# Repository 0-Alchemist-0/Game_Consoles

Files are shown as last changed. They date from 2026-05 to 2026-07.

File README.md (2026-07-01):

# Game Consoles

Custom WiFi handheld game consoles built with an Arduino Nano ESP32, a
Waveshare 3.5 inch ILI9488 SPI display, FT6336 capacitive touch, microSD RAW
assets, and a buzzer.

Current sketch: `Game_Consoles.ino`

Current firmware metadata:

- Version: `Version 9.3`
- Build ID: `GC-V93-2026070120`
- Build ID format: `GC-V<major><minor>-<YYYYMMDDHH>`

## Overview

The project boots into an arcade-style home screen, plays an optional RAW565
intro from the SD card, and provides a multi-page games menu. Games can be
played locally on one console or, where supported, over WiFi using Host/Join.

The UI is designed for portrait mode:

- Screen width: `320`
- Screen height: `480`
- Rotation: `0`
- Display colors are inverted in firmware with `INVERT_DISPLAY_COLORS = true`

The sketch draws directly to the display using targeted redraws and game-level
dirty rectangles. It does not use the old full-screen canvas framebuffer
approach described by earlier README versions.

## Hardware

Main board:

- Arduino Nano ESP32

Display:

- Waveshare 3.5 inch SPI TFT
- Controller: ILI9488
- Library class: `Arduino_ILI9488_18bit`

Touch:

- FT6336 capacitive touch controller
- I2C address: `0x38`

Storage:

- microSD card on the same SPI bus as the display
- SD assets are RAW565 files, usually `320x480`

Audio:

- Buzzer on GPIO4
- Used for menu clicks, SFX, and the background menu melody

## Pin Configuration

The sketch uses ESP32 GPIO numbering.

| Function | GPIO | Arduino Nano ESP32 label | Header note |
| --- | ---: | --- | --- |
| LCD CS | 21 | D10 | JP2-3 |
| LCD DC | 18 | D9 | JP2-4 |
| LCD RST | 17 | D8 | JP2-5 |
| LCD MOSI | 38 | D11 / MOSI | JP2-2 |
| LCD MISO | 47 | D12 / MISO | JP2-1 |
| LCD SCLK | 48 | D13 / SCK | JP1-1 |
| SD CS | 8 | D5 | JP2-8 |
| Touch INT | 6 | D3 | JP2-10 |
| Touch RST | 7 | D4 | JP2-9 |
| I2C SDA | 11 | A4 / SDA | JP1-8 |
| I2C SCL | 12 | A5 / SCL | JP1-9 |
| Buzzer | 4 | A3 | JP1-7 |

SD SPI frequency:

```cpp
static const int SD_SPI_FREQ = 49000000;
```

If the SD card is unstable with your wiring, lower this value in the sketch.

## Required Libraries

Install these in Arduino IDE / Arduino CLI:

- `Arduino_GFX_Library`
- ESP32 board package for Arduino Nano ESP32

The sketch also uses standard ESP32/Arduino libraries:

- `Wire`
- `WiFi`
- `Preferences`
- `SPI`
- `SD`
- `FS`
- `esp_now`
- `esp_wifi`
- `esp_system`

## Main Screens

Home screen:

- `GAMES`
- `SETTINGS`
- `EXIT`
- Version and Build ID are displayed in small text at the bottom

Games menu pages:

- Page 1: Tic Tac Toe, Rock-Paper-Scissors, Tanks Wars
- Page 2: Snake, Breakout, Pong, Ranch Rush
- Page 3: Hex Pipes, Frogger

Most game menus use:

- `LOCAL`
- `HOST`
- `JOIN`
- `RESET SCORE`
- `BACK`

## Settings

The Home screen `SETTINGS` button opens two settings categories.

### Music

- `MUSIC ON/OFF`
- `SFX ON/OFF`

Music controls the background arcade melody while not in a game.
SFX controls button and game sound effects.

Settings are saved persistently in ESP32 flash using `Preferences`.

### WiFi

WiFi settings allow:

- Default Host SSID selection from the built-in epic SSID list
- Host IP editing through four numeric fields
- Numeric keypad input
- Save button

Default Host IP:

```text
192.168.10.1
```

Network password for Host and Join:

```text
Alchemist2026
```

Network TCP port:

```text
3333
```

## Network Flow

Host:

1. Select `HOST` from a game menu.
2. Select an SSID from the built-in list.
3. Confirm or edit the Host IP.
4. The console starts a WiFi access point.
5. The host waits for the opponent.

Join:

1. Select `JOIN` from a game menu.
2. Scan/select an available WiFi network.
3. Confirm or edit the Host IP.
4. Join connects using the fixed password `Alchemist2026`.
5. The game starts when the socket connects.

The shared WiFi game protocol uses line-based TCP messages over port `3333`.

## Games

| Game | Local | Network Host/Join | Notes |
| --- | --- | --- | --- |
| Tic Tac Toe | Yes | Yes | Local X/O play, WiFi X/O play, persistent score |
| Rock-Paper-Scissors-Lizard-Spock | Yes | Yes | Uses SD RAW result images when available |
| Tanks Wars | Yes | Yes | Artillery-style tanks, destructible terrain, synced terrain seed |
| Breakout | Yes | Yes | First network player to lose all lives loses |
| Pong | Yes | Yes | Host-authoritative ball physics and synced paddles |
| Snake | Yes | Yes | Two-player network snakes with different colors |
| Ranch Rush | Yes | Yes | Lane-based lasso game with two visible network players |
| Frogger | Yes | Yes | Two visible network frogs, shared lanes/logs |
| Hex Pipes | Yes | Yes | Shared puzzle seed, P1/P2 move counters, solve race |

Each game has a score reset option in its game menu. High score or score data is
stored in ESP32 flash with separate `Preferences` namespaces per game.

<p align="center">
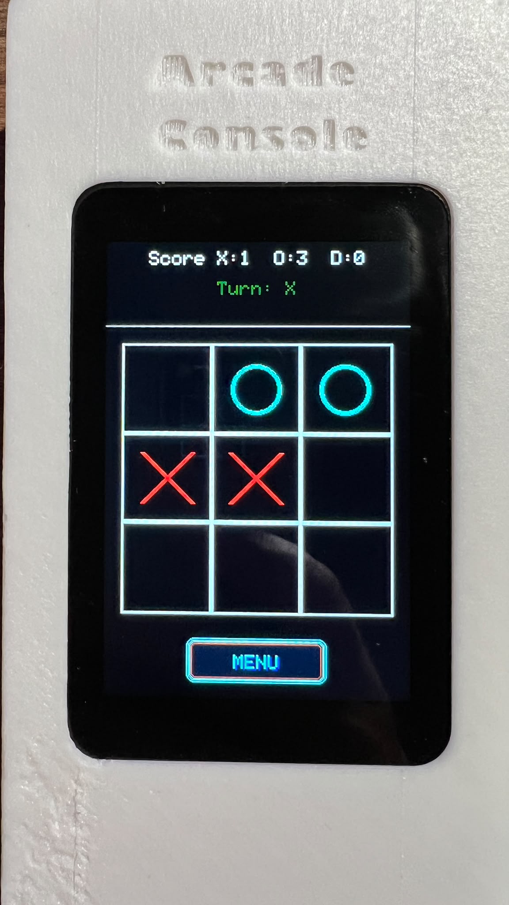
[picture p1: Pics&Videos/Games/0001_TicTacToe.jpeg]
  
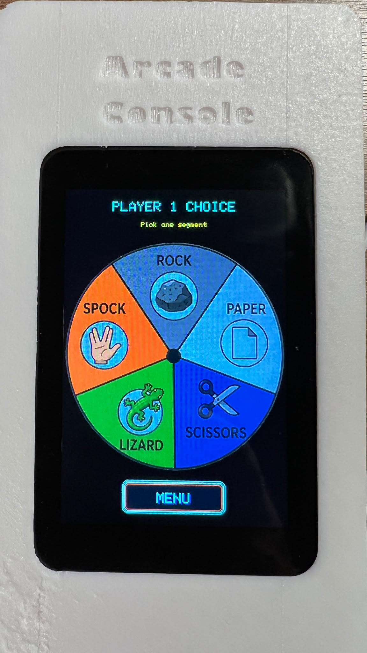
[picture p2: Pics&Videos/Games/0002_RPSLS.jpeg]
  
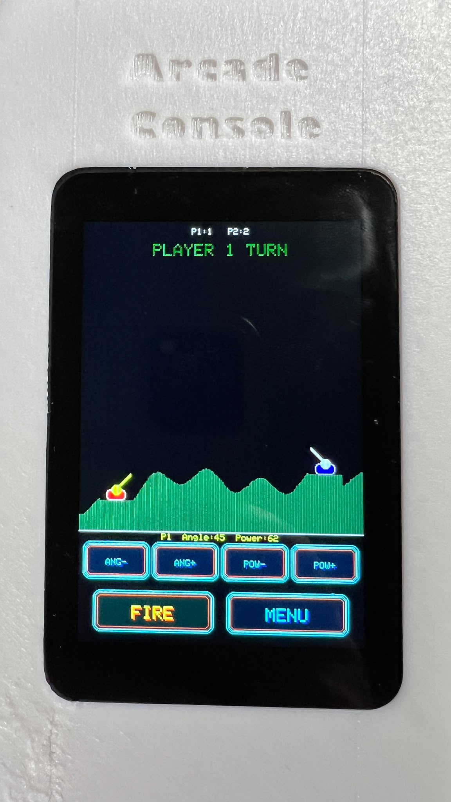
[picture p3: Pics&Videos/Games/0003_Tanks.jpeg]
  
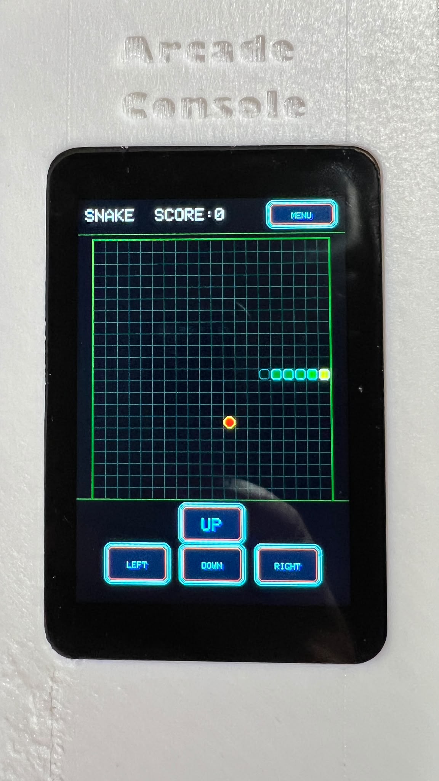
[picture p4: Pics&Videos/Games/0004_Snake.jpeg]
  
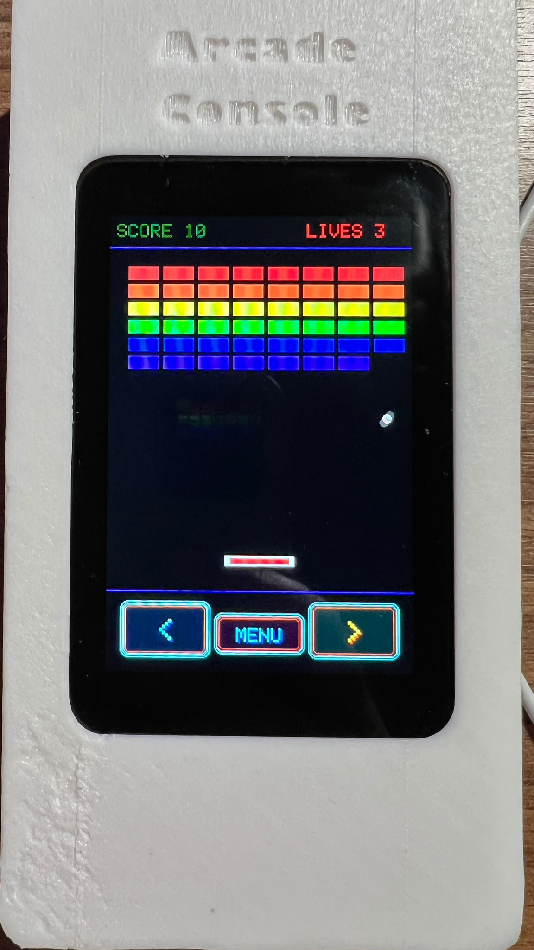
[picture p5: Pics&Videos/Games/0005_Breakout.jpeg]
  
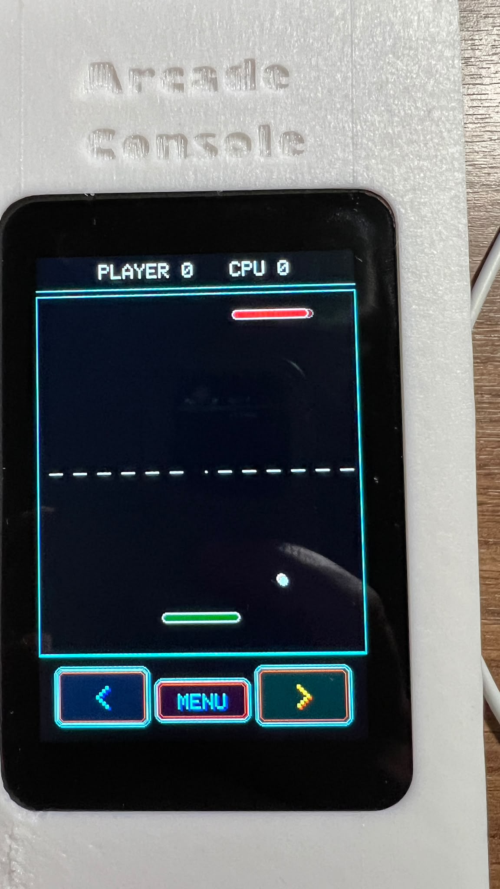
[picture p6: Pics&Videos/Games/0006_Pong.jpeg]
  
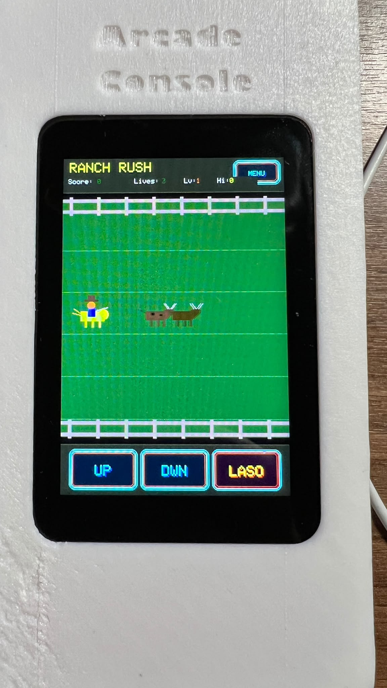
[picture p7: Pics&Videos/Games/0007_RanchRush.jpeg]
  
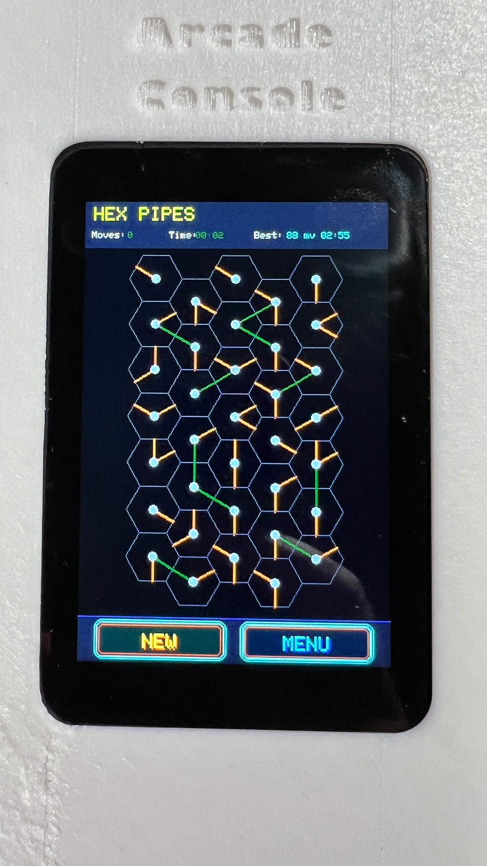
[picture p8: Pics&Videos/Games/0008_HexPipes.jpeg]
  
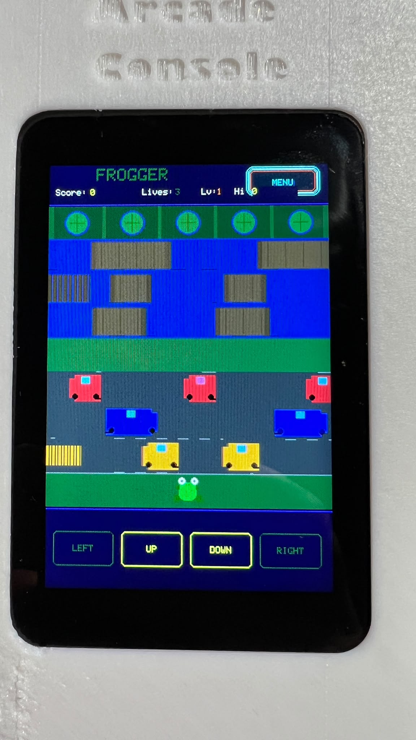
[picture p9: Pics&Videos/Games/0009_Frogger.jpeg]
  
</p>

## SD Card Assets

The console can run with generated fallback screens when assets are missing, but
the intended UI uses RAW565 files from the microSD card.

Important SD paths:

```text
/intro/frame_000.raw ... /intro/frame_074.raw
/home_screen/background.raw
/home_screen/button_games.raw
/home_screen/button_settings.raw
/home_screen/button_exit.raw
/games_screen/games_background.raw
/tictactoe_game/tictactoe_background.raw
/RPSLS_game/main_screen/rock_paper_scissors_background.raw
/RPSLS_game/general/rpsls_wheel.raw
/RPSLS_game/local/player1_wins/*.raw
/RPSLS_game/local/player2_wins/*.raw
/RPSLS_game/local/draw/*.raw
/RPSLS_game/win/*.raw
/RPSLS_game/lose/*.raw
```

RAW image format:

- RGB565
- No header
- Full-screen assets are `320x480`
- Intro frames are also portrait `320x480`

The repository `SD_card` folder contains SD card content and preview PNGs.

## Persistent Data

Stored with `Preferences`:

- Tic Tac Toe score
- RPSLS score
- Tanks Wars score
- Breakout high score
- Pong score
- Snake high score
- Ranch Rush high score
- Frogger high score
- Hex Pipes best moves and best time
- Default WiFi/Host IP settings
- Music and SFX settings

## Notes

- Keep only one active Arduino sketch file in the project folder to avoid
  duplicate symbol errors.
- The active sketch should be `Game_Consoles.ino`.
- If you copy the project into Arduino IDE, the folder name should match the
  active `.ino` file or you should open the correct sketch directly.
- If SD assets do not load, the firmware falls back to generated screens for
  the main UI and several game menus.
- For network play, use the same firmware version on both consoles.

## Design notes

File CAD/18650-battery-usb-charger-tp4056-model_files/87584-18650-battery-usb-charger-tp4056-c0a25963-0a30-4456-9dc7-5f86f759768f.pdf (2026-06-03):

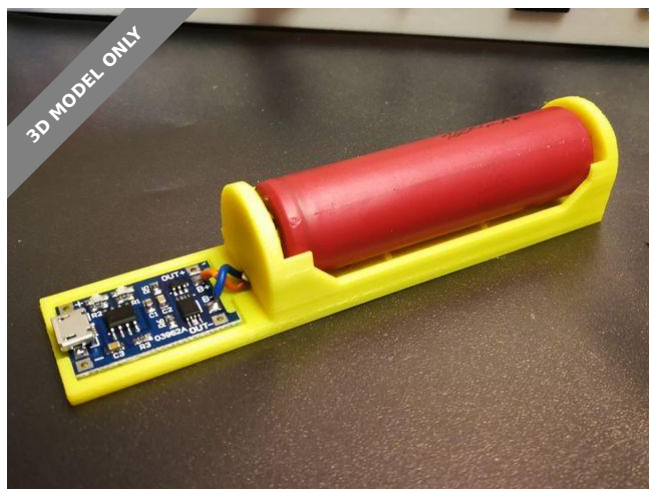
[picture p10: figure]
3D MODEL ONLY

### Summary

This is a charging holder for a single 18650 lithium ion battery. It uses the TP4056 charging board, that you can get...

Hobby & Makers (https://printables.com/model?categoryId=48) > Electronics (https://printables.com/model?categoryId=52)

Tags: 18650 | 18650battery | charger | contact | lithium
lithiumion | lithiumbattery | usb | thingiverse

This is a charging holder for a single 18650 lithium ion battery. It uses the TP4056 charging board, that you can get easy on eBay.
(Search for "lithium usb charger" or "TP4056")

The battery contacts used are 10x10mm but you can use whichever one you want.

The standard version fits unprotected cells of 65mm length, the "_protected" version fits protected cells of 68mm length

If you need one of my things printed or you want to suggest a modification on a part please drop me a message!

If you print one of my things i would be happy about some feedback and a make!

Chrismettal - Binary-6 (https://printables.com/@ChrismettalBinary6)

## 18650 Battery USB

### Charger TP4056

VIEW IN BROWSER (https://printables.com/model/87584-18650-battery-usb-charger-tp4056)

updated 6. 5. 2023 | published 6. 5. 2023

## Model files

If you like my things please consider supporting my caffeine addiction! (https://github.com/Chrismettal#donations)

### This remix is based on

18650 Battery USB Charger TP4056 by Chrismettal

Find source .stl files on Thingiverse.com (https://www.thingiverse.com/thing:2248981)

### License

This work is licensed under a
Creative Commons (4.0 International License)

Attribution-ShareAlike (http://creativecommons.org/licenses/by-sa/4.0/)

✖ | Sharing without ATTRIBUTION
✔ | Remix Culture allowed
✔ | Commercial Use
✔ | Free Cultural Works
✔ | Meets Open Definition

single_18650_v3.stl

single-18650_protected-v3.stl

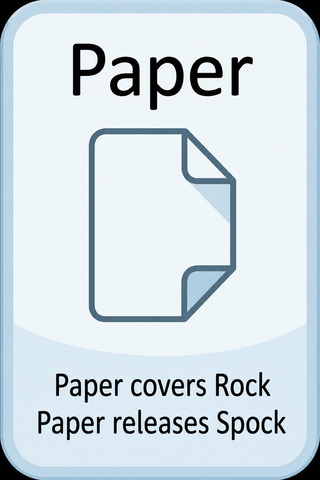
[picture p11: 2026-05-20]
SD_card/RPSLS_game/general/paper_preview.png

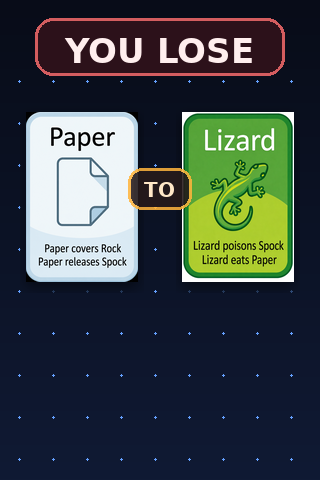
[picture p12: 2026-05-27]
SD_card/RPSLS_game/lose/lose_paper_to_lizard_preview.png

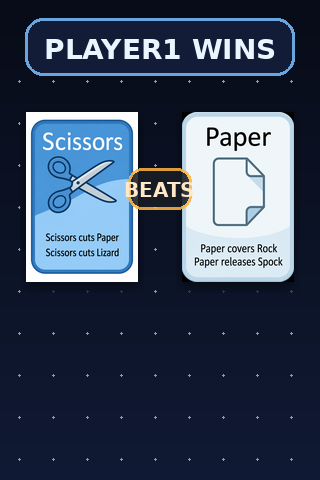
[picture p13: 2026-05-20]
SD_card/RPSLS_game/local/player1_wins/win_scissors_cuts_paper_preview.png

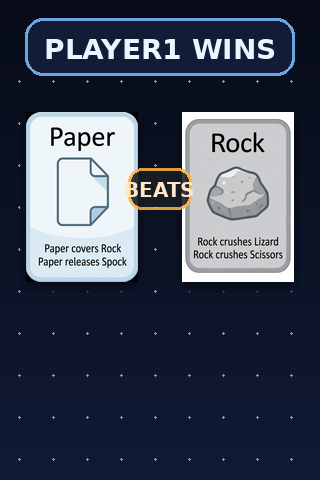
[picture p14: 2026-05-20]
SD_card/RPSLS_game/local/player1_wins/win_paper_covers_rock_preview.png

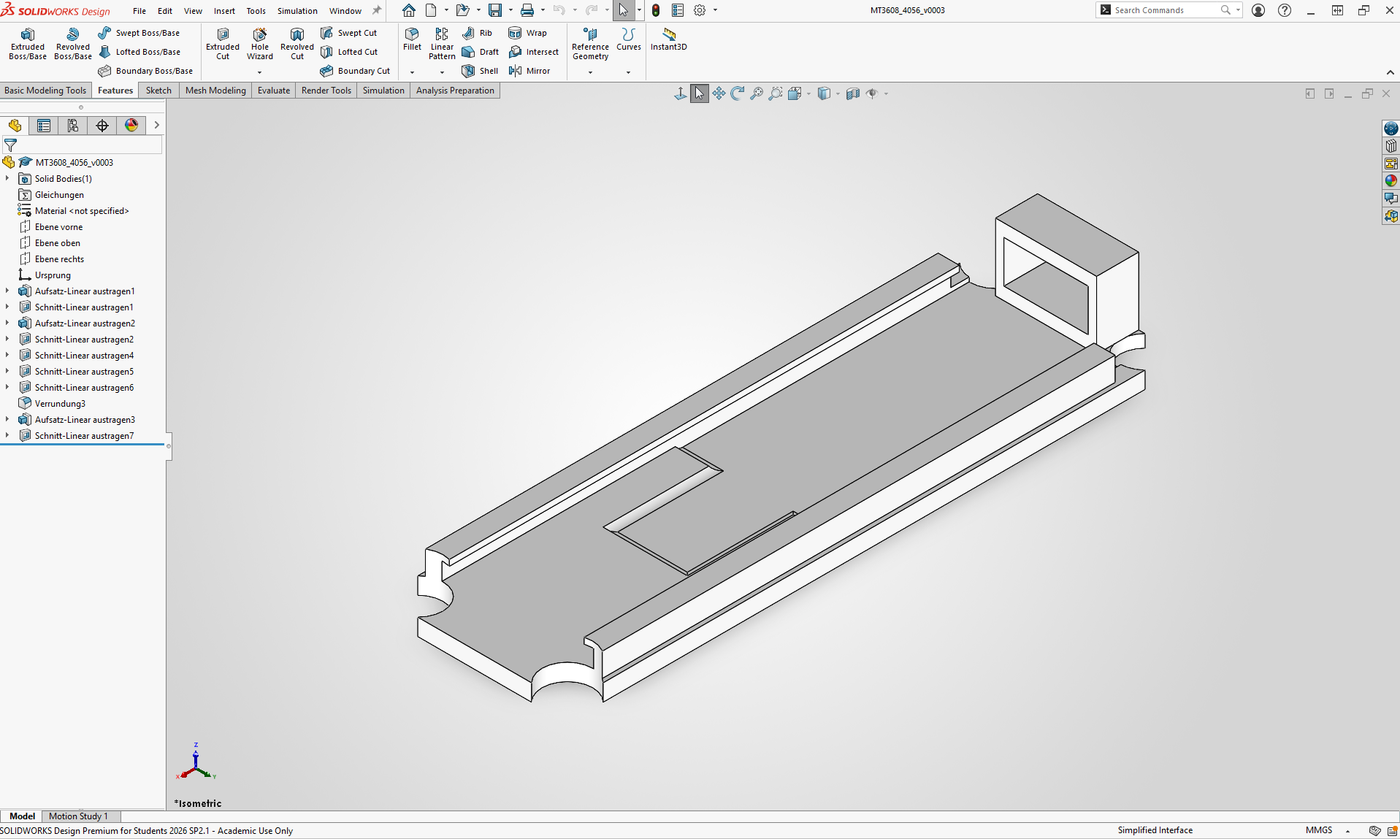
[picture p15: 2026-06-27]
Pics&Videos/00007_Support rail for the power module, designed for internal placement of the MT3608TP4056-related electronics..png

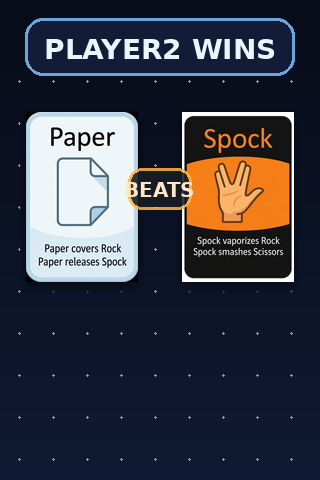
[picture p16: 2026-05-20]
SD_card/RPSLS_game/local/player2_wins/win_paper_releases_spock_preview.png

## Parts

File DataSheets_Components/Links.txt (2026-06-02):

https://docs.arduino.cc/hardware/nano/

https://www.waveshare.com/3.5inch-capacitive-touch-lcd.htm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

https://lvgl.io/tools/imageconverter
https://sourceforge.net/projects/lcd-image-converter/

https://www.printables.com/model/553096-tp4056-usb-c-model-li-ion-charge-circuit-3d-model/files
https://www.thingiverse.com/thing:1029881
https://www.printables.com/model/87584-18650-battery-usb-charger-tp4056
https://www.printables.com/model/1004227-lithium-battery-charger-li-ion-module-tp4056-usb-c/files
https://www.printables.com/model/131214-18650-minimal-holder

https://www.printables.com/model/59190-1s2p-18650-vase-mode-holder-with-tp4056-mt3608-boa
https://www.printables.com/model/1009486-enclosure-for-arduino-nano-esp32

Informatii USB-C https://electronics.stackexchange.com/questions/534304/finding-the-exterior-dimensions-of-a-usb-type-c-receptacle

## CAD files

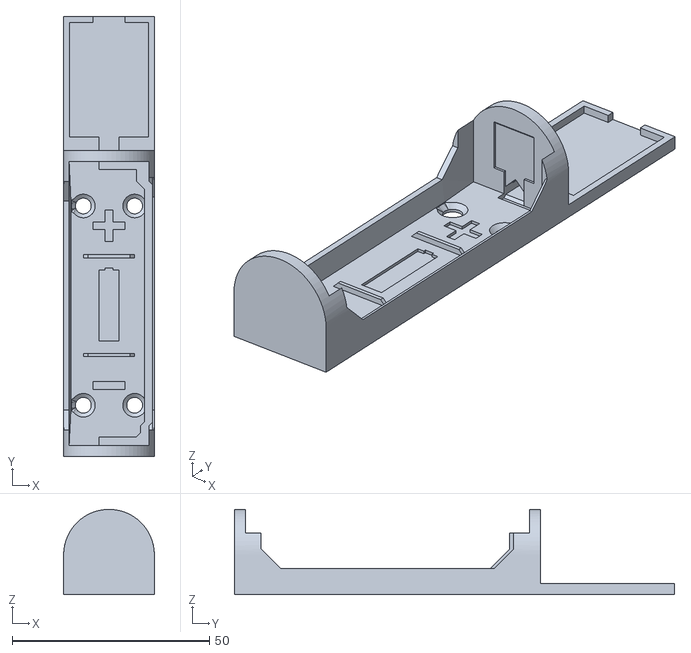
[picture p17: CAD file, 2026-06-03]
CAD/18650-battery-usb-charger-tp4056-model_files/Single 18650_Protected v3.stl
23.0 x 111.5 x 21.6

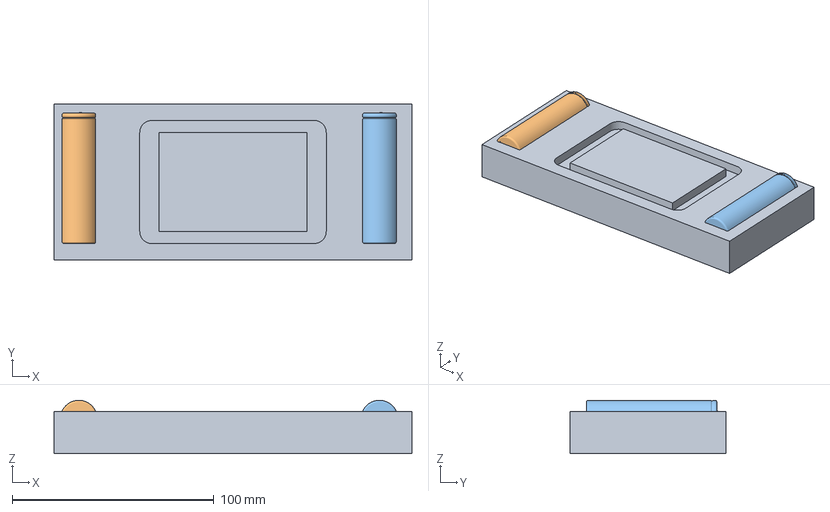
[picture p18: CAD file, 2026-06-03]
CAD/Carcasa_v0002.FCStd
177.4 x 77.5 x 26.4 mm
18650_Refrence_Cell
18650_Refrence_Cell001

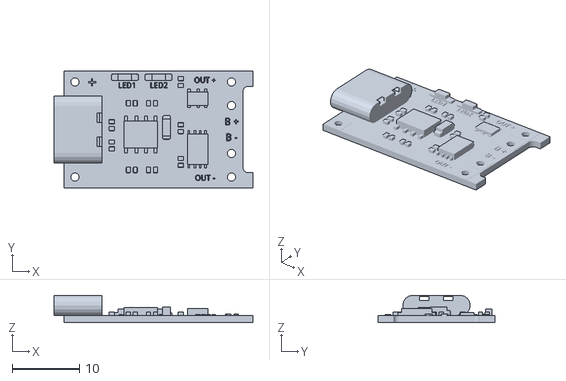
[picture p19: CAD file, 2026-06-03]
CAD/lithium-battery-charger-li-ion-module-tp4056-usb-c-mock-up-model_files/liion-charge-module-hw-373-usb-c.stl
29.5 x 17.3 x 4.07

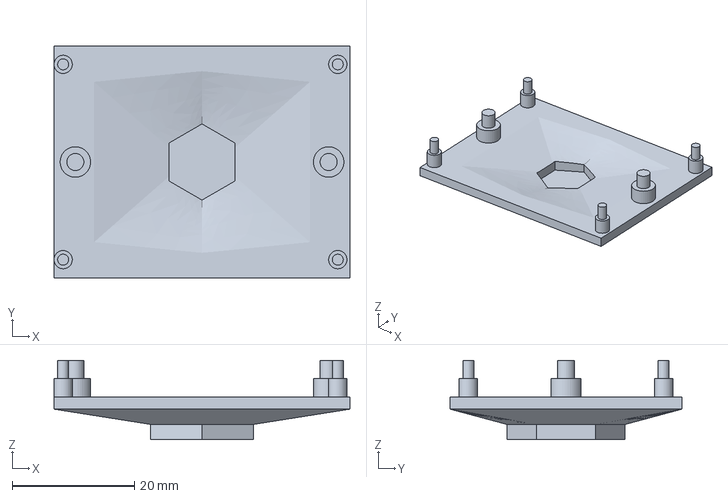
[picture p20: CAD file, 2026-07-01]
SolidWorks/Creality/Arhiva/Support_PCB_v0004.3mf
48.5 x 38.0 x 13.0 mm

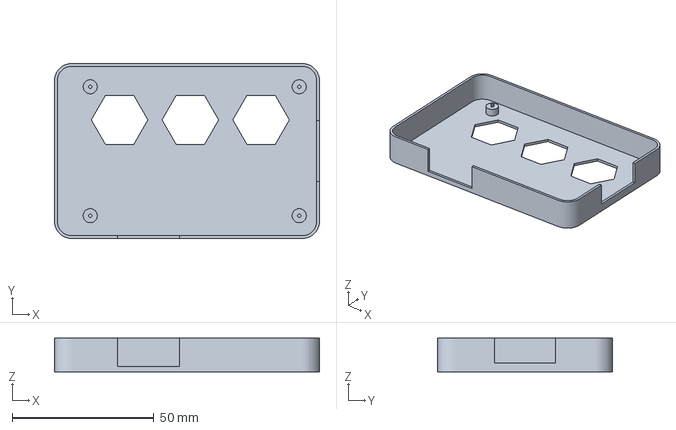
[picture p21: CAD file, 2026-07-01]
SolidWorks/Creality/Inside_Nano_Support_v1000.3mf
93.6 x 61.8 x 12.0 mm

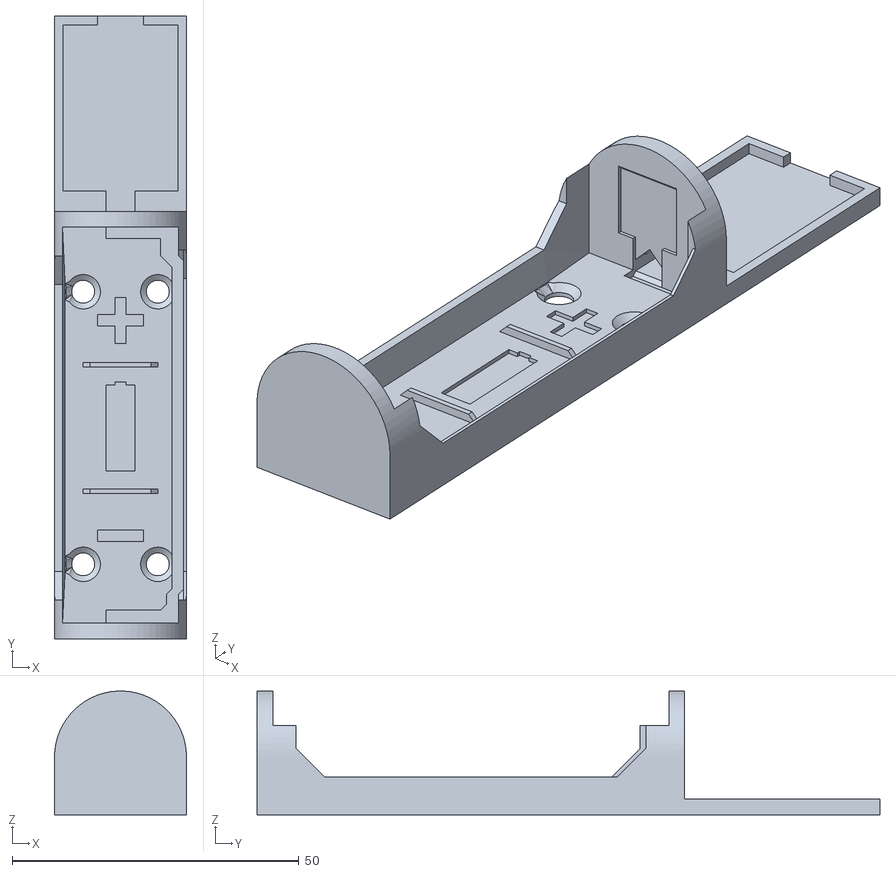
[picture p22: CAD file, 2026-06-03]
CAD/18650-battery-usb-charger-tp4056-model_files/Single_18650_v3.stl
23.0 x 108.5 x 21.6

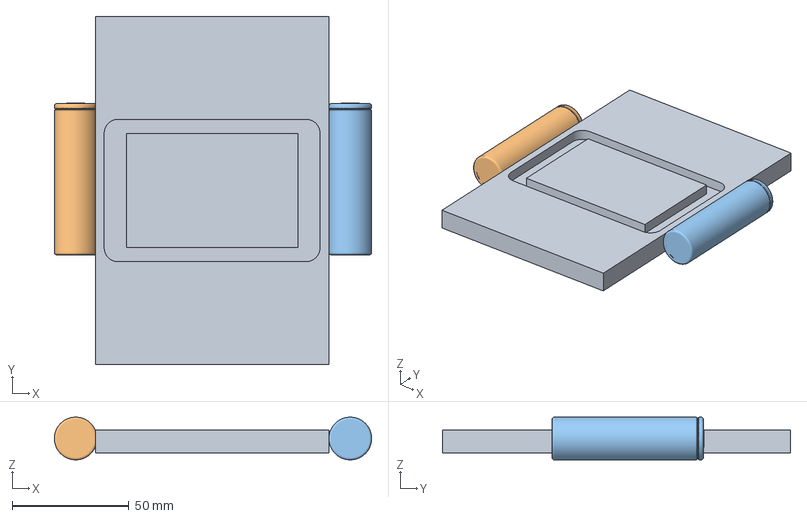
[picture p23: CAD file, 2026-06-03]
CAD/Carcasa_landscape_v0003.FCStd
135.9 x 149.0 x 18.3 mm
18650_Refrence_Cell
18650_Refrence_Cell001

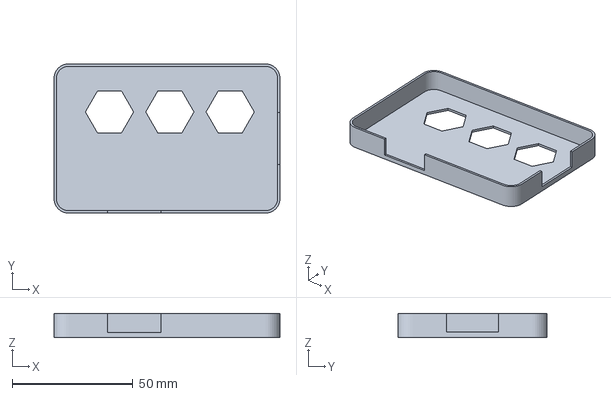
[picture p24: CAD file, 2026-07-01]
SolidWorks/Creality/Arhiva/Inside_Nano_Support_v0007.3mf
93.6 x 61.8 x 10.0 mm

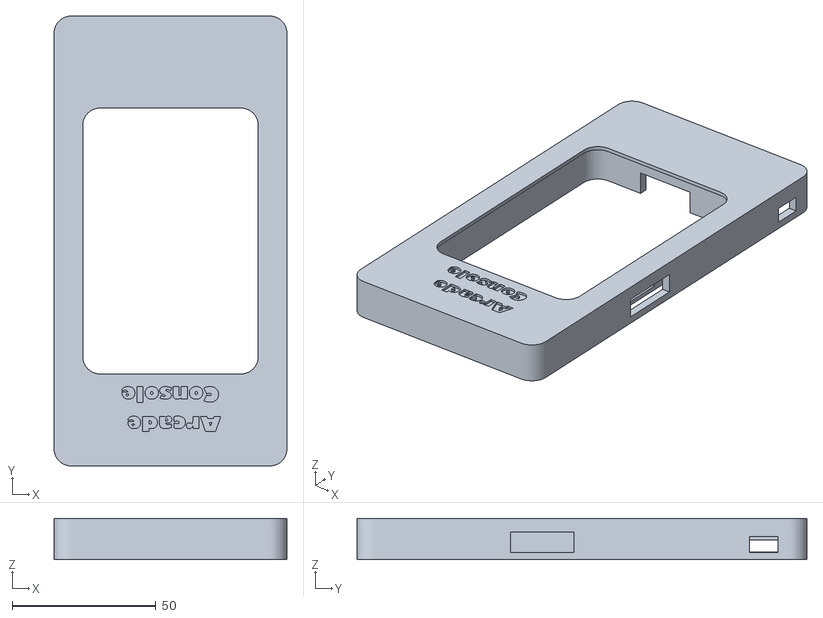
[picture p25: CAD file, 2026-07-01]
SolidWorks/Creality/DisplayCase_v1001.STL
81.0 x 156.4 x 14.3

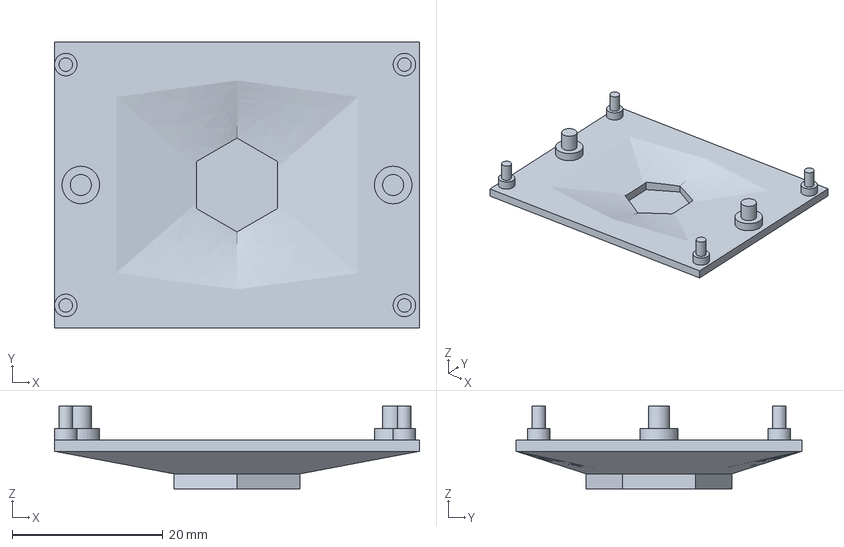
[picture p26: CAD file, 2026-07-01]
SolidWorks/Creality/Support_PCB_v0005.3mf
48.5 x 38.0 x 11.0 mm

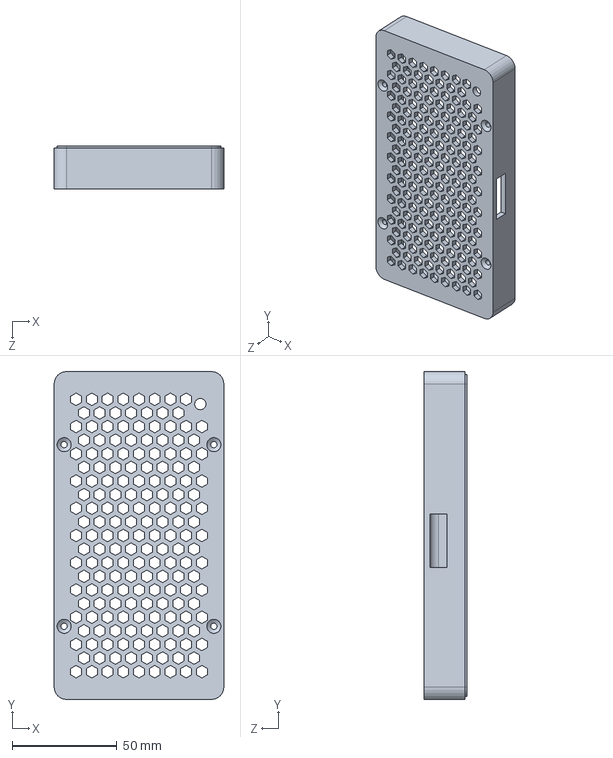
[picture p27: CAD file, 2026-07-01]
SolidWorks/DisplayCase_Back_v0012_simple.SLDPRT
81.0 x 156.4 x 20.6 mm

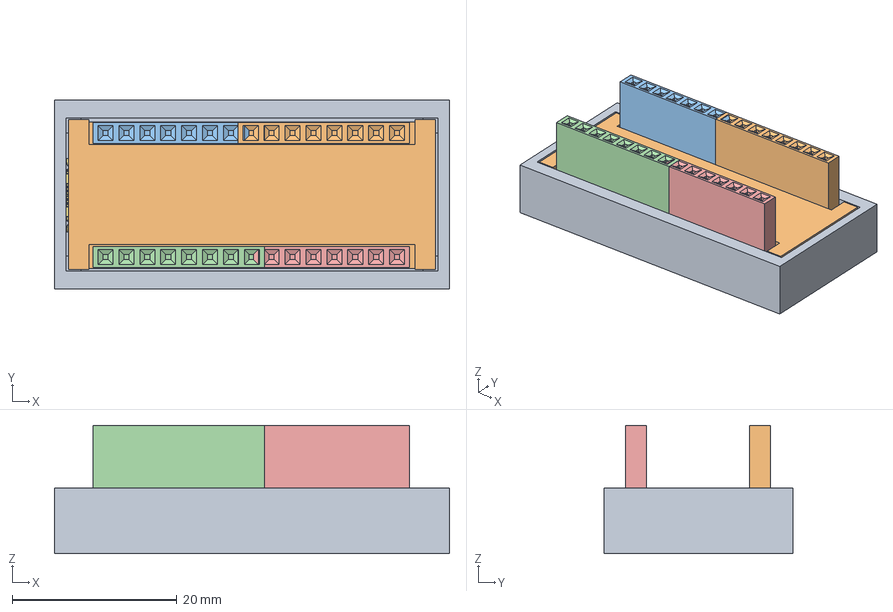
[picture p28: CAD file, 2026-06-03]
CAD/Carcasa Arduino Nano ESP32.FCStd
48.0 x 23.0 x 15.6 mm
RES-0201
RES-0202
RES-0203
CAP-0402
Extruded
CAP-0201
Extruded001
Extruded002
Extruded003
Extruded004
Extruded005
Extruded006
Extruded007
Extruded008
Extruded009
pins
logo
Extruded010
Extruded011
Extruded012
Extruded013
Extruded014
Extruded015
Extruded016
Extruded017
Extruded018
Extruded019
Extruded020
Extruded021
Extruded022
Extruded023
Extruded024
Extruded025
Extruded026
Extruded027
Extruded028
Extruded029
Extruded030
Extruded031
Extruded032
Extruded033
Extruded034
Extruded035
Extruded036
Extruded037
Extruded038
Extruded039
Extruded040
Extruded041
Extruded042
Extruded043
Extruded044
Extruded045
Extruded046
Extruded047
Extruded048
label_8x8
logo_x_4mm
logo_o_4mm
logo_l_4mm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

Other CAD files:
SolidWorks/Inside_Nano_Support_v1000.SLDPRT
SolidWorks/DisplayCase_v1000_simple.SLDPRT
CAD/Carcasa_landscape_v0002.FCStd
SolidWorks/Creality/Arhiva/DisplayCase_v1000_simple.3mf
SolidWorks/Creality/DisplayCase_Back_v1000_simple.3mf
SolidWorks/DisplayCase_Back_v1000_simple.SLDPRT
CAD/18650-minimal-holder-model_files/18650 minimal holder.step
CAD/18650-minimal-holder-model_files/18650_minimal_holder.stl
CAD/1s2p-18650-vase-mode-holder-with-tp4056-mt3608-boards-slot-model_files/18650x2vaseCctHldr.stl
CAD/Carcasa_v0001-BodyFillet.step
SolidWorks/016_Suport_OLED_PCB-PCB_EPȘZON.step
SolidWorks/016_Suport_OLED_PCB-Support_OLED.SLDPRT
SolidWorks/016_Suport_OLED_PCB-Support_OLED.iges
SolidWorks/016_Suport_OLED_PCB-Support_OLED.step
SolidWorks/18650x2vaseCctHldr.SLDPRT
SolidWorks/18650x2vaseCctHldr.STL
SolidWorks/3.5inch Capacitive Touch LCD.dwg
SolidWorks/Assembly_test.SLDDRW
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

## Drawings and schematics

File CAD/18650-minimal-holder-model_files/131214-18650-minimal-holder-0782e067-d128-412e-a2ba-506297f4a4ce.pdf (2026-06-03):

## 18650 minimal

## holder

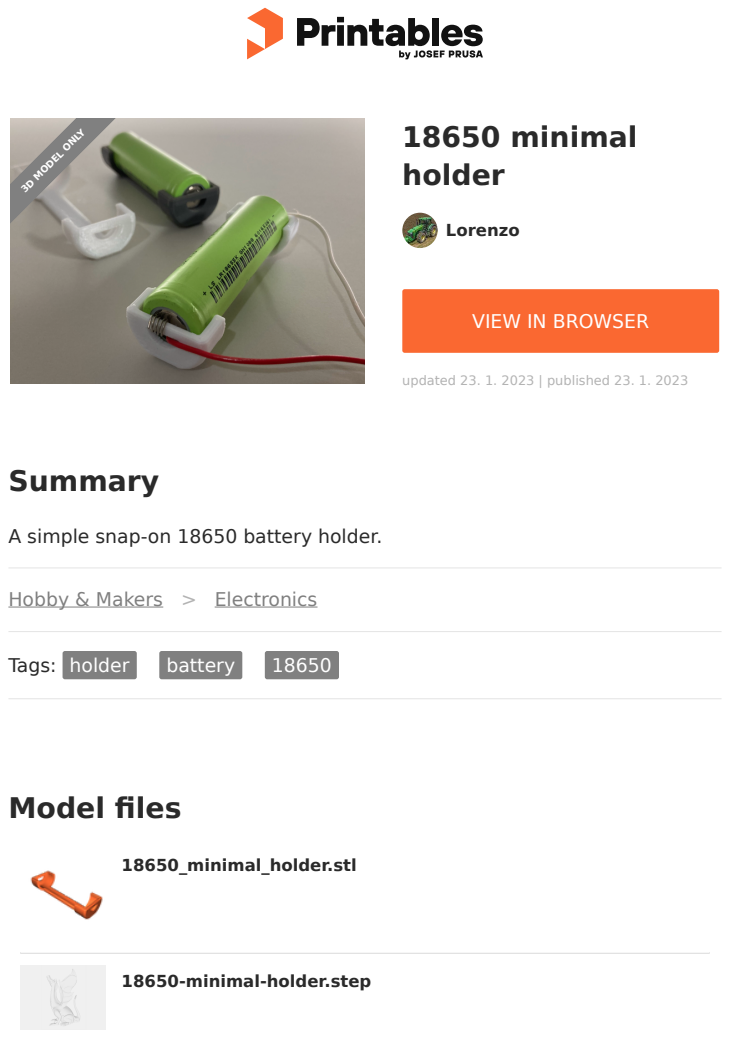
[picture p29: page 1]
Model files; Summary; Hobby & Makers; Electronics; Tags: holder; battery; Lorenzo; updated 23. 1. 2023 | published 23. 1. 2023; 18650_minimal_holder.stl; 3D MODEL ONLY

VIEW IN BROWSER (https://printables.com/model/131214-18650-minimal-holder)

A simple snap-on 18650 battery holder.

18650-minimal-holder.step

### License

This work is licensed under a
Creative Commons (4.0 International License)

Attribution (http://creativecommons.org/licenses/by/4.0/)

✖ | Sharing without ATTRIBUTION
✔ | Remix Culture allowed
✔ | Commercial Use
✔ | Free Cultural Works
✔ | Meets Open Definition

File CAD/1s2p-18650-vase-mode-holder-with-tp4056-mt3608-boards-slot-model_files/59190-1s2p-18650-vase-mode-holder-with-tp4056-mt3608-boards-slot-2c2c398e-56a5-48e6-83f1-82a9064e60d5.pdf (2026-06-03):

# 1S2P 18650 Vase

## Mode Holder With

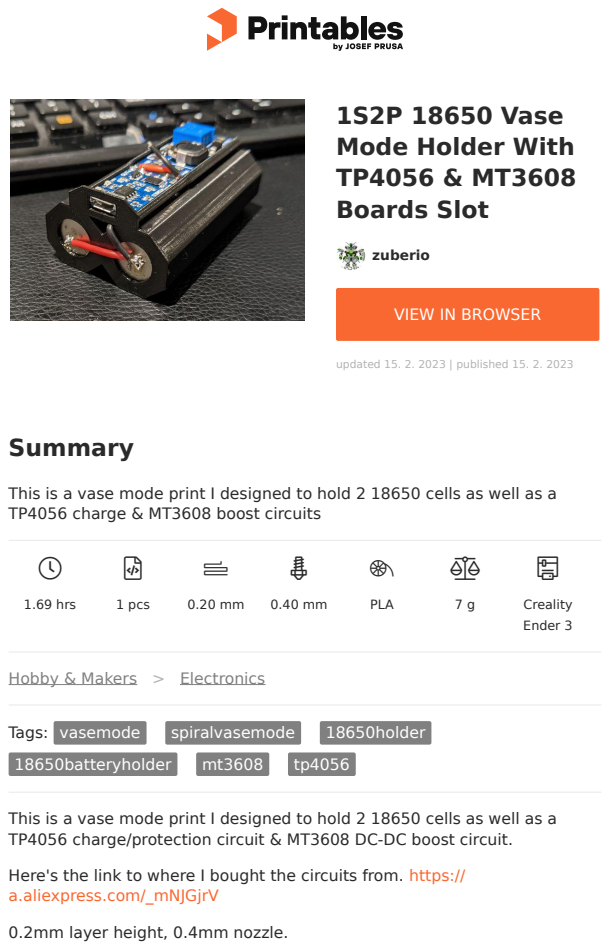
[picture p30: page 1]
1.69 hrs; 1 pcs; PLA; Creality; Ender 3; Summary; Hobby & Makers; Electronics; Tags: vasemode; spiralvasemode; 18650holder; 18650batteryholder; zuberio; Boards Slot; updated 15. 2. 2023 | published 15. 2. 2023

VIEW IN BROWSER (https://printables.com/model/59190-1s2p-18650-vase-mode-holder-with-tp4056-mt3608-boa)

This is a vase mode print I designed to hold 2 18650 cells as well as a
TP4056 charge & MT3608 boost circuits

TP4056 charge/protection circuit & MT3608 DC-DC boost circuit.

Here's the link to where I bought the circuits from. https://
a.aliexpress.com/_mNJGjrV

0.2mm layer height, 0.4mm nozzle.

# Model files

## Print files

h PLA | k 0.40 mm | f 0.20 mm | 1.69 hrs | 7 g | d Creality Ender 3

## License

This work is licensed under a
Creative Commons (4.0 International License)

Attribution-ShareAlike (http://creativecommons.org/licenses/by-sa/4.0/)

✖ | Sharing without ATTRIBUTION
✔ | Remix Culture allowed
✔ | Commercial Use
✔ | Free Cultural Works
✔ | Meets Open Definition

18650x2vaseccthldr.stl

1h41m-pla.gcode

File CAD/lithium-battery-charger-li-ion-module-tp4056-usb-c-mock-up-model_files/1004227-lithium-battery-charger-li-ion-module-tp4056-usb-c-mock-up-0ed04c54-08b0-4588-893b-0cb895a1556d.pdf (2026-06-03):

## Lithium Battery Charger Li-ion

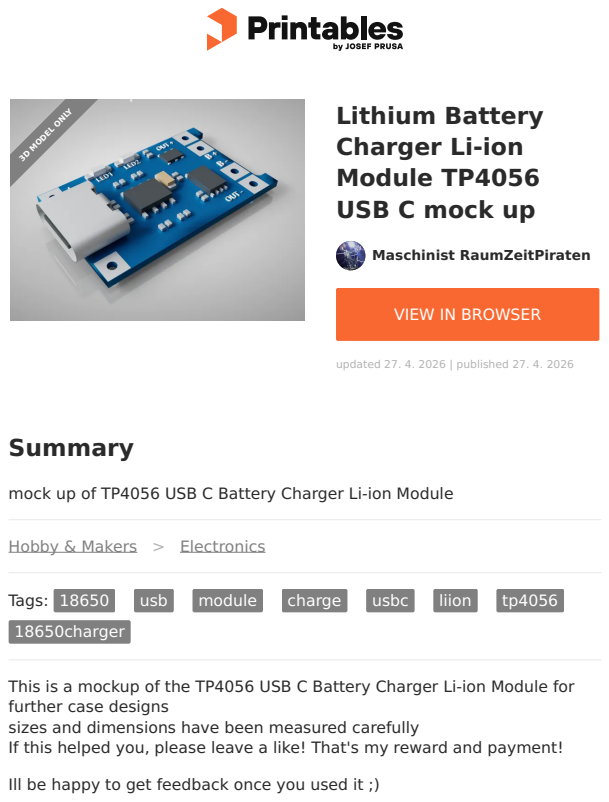
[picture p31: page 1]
Summary; Tags:; usb; module; charge; usbc; liion; 18650charger; Maschinist RaumZeitPiraten; updated 27. 4. 2026 | published 27. 4. 2026; 3D MODEL ONLY

Module TP4056
USB C mock up

VIEW IN BROWSER (https://printables.com/model/1004227-lithium-battery-charger-li-ion-module-tp4056-usb-c)

mock up of TP4056 USB C Battery Charger Li-ion Module

Hobby & Makers (https://printables.com/model?categoryId=48) > Electronics (https://printables.com/model?categoryId=52)

This is a mockup of the TP4056 USB C Battery Charger Li-ion Module for
further case designs
sizes and dimensions have been measured carefully
If this helped you, please leave a like! That's my reward and payment!

Ill be happy to get feedback once you used it ;)

## Model files

## License

This work is licensed under a
Creative Commons (4.0 International License)

Attribution—Noncommercial—Share Alike (http://creativecommons.org/licenses/by-nc-sa/4.0/)

✖ | Sharing without ATTRIBUTION
✔ | Remix Culture allowed
✖ | Commercial Use
✖ | Free Cultural Works
✖ | Meets Open Definition

liion-charge-module-hw-373-usb-c.stl

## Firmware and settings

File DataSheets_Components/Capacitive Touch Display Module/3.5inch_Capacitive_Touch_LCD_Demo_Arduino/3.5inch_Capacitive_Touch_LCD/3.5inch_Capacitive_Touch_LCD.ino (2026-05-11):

#include <Arduino_GFX_Library.h>
#include <Wire.h>

// ---------------- PINI ----------------
static const int PIN_LCD_CS   = 10;
static const int PIN_LCD_DC   = 9;
static const int PIN_LCD_RST  = 8;
static const int PIN_LCD_BL   = 6;

static const int PIN_TP_INT   = 3;
static const int PIN_TP_RST   = 4;
static const int PIN_SD_CS    = 5;   // optional, nefolosit aici

// FT6336U touch controller
static const uint8_t FT6336_ADDR = 0x38;

// ---------------- DISPLAY ----------------
// Arduino_GFX documentează declarația simplă cu Arduino_HWSPI(DC, CS). :contentReference[oaicite:1]{index=1}
Arduino_DataBus *bus = new Arduino_HWSPI(
  PIN_LCD_DC,
  PIN_LCD_CS
);

Arduino_GFX *gfx = new Arduino_ST7796(
  bus,
  PIN_LCD_RST,
  1,
  true,
  320,
  480
);

// ---------------- JOC ----------------
char board[3][3];
char currentPlayer = 'X';
bool gameOver = false;
char winner = ' ';

int screenW = 320;
int screenH = 480;

int boardX = 20;
int boardY = 70;
int boardSize = 280;
int cellSize = boardSize / 3;

int resetBtnX = 90;
int resetBtnY = 380;
int resetBtnW = 140;
int resetBtnH = 50;

unsigned long lastTouchTime = 0;
const unsigned long touchDebounceMs = 180;

// ---------------- TOUCH FT6336U ----------------
uint8_t tpReadReg(uint8_t reg) {
  Wire.beginTransmission(FT6336_ADDR);
  Wire.write(reg);
  if (Wire.endTransmission(false) != 0) return 0;
  Wire.requestFrom((int)FT6336_ADDR, 1);
  if (Wire.available()) return Wire.read();
  return 0;
}

bool readTouchRaw(uint16_t &x, uint16_t &y) {
  uint8_t points = tpReadReg(0x02) & 0x0F;
  if (points == 0) return false;

  uint8_t xh = tpReadReg(0x03);
  uint8_t xl = tpReadReg(0x04);
  uint8_t yh = tpReadReg(0x05);
  uint8_t yl = tpReadReg(0x06);

  x = ((xh & 0x0F) << 8) | xl;
  y = ((yh & 0x0F) << 8) | yl;

  return true;
}

bool readTouchScreen(int &sx, int &sy) {
  uint16_t rx, ry;
  if (!readTouchRaw(rx, ry)) return false;

  sx = map(ry, 0, 480, 0, screenW);
  sy = map(rx, 0, 320, 0, screenH);

  if (sx < 0) sx = 0;
  if (sx >= screenW) sx = screenW - 1;
  if (sy < 0) sy = 0;
  if (sy >= screenH) sy = screenH - 1;

  return true;
}

// ---------------- UTILITARE JOC ----------------
void resetGame() {
  for (int r = 0; r < 3; r++) {
    for (int c = 0; c < 3; c++) {
      board[r][c] = ' ';
    }
  }
  currentPlayer = 'X';
  gameOver = false;
  winner = ' ';
}

bool boardFull() {
  for (int r = 0; r < 3; r++) {
    for (int c = 0; c < 3; c++) {
      if (board[r][c] == ' ') return false;
    }
  }
  return true;
}

char checkWinner() {
  for (int r = 0; r < 3; r++) {
    if (board[r][0] != ' ' &&
        board[r][0] == board[r][1] &&
        board[r][1] == board[r][2]) {
      return board[r][0];
    }
  }

  for (int c = 0; c < 3; c++) {
    if (board[0][c] != ' ' &&
        board[0][c] == board[1][c] &&
        board[1][c] == board[2][c]) {
      return board[0][c];
    }
  }

  if (board[0][0] != ' ' &&
      board[0][0] == board[1][1] &&
      board[1][1] == board[2][2]) {
    return board[0][0];
  }

  if (board[0][2] != ' ' &&
      board[0][2] == board[1][1] &&
      board[1][1] == board[2][0]) {
    return board[0][2];
  }

  if (boardFull()) return 'D';
  return ' ';
}

// ---------------- DESENARE ----------------
void drawCenteredText(const char *txt, int y, int size, uint16_t color) {
  int16_t x1, y1;
  uint16_t w, h;
  gfx->setTextSize(size);
  gfx->getTextBounds((char*)txt, 0, y, &x1, &y1, &w, &h);
  int x = (screenW - w) / 2;
  gfx->setCursor(x, y);
  gfx->setTextColor(color);
  gfx->print(txt);
}

void drawStatus() {
  gfx->fillRect(0, 0, screenW, 55, RGB565_BLACK);

  if (!gameOver) {
    char msg[32];
    snprintf(msg, sizeof(msg), "Randul: %c", currentPlayer);
    drawCenteredText(msg, 18, 2, RGB565_WHITE);
  } else {
    if (winner == 'D') {
      drawCenteredText("Egal!", 18, 2, RGB565_YELLOW);
    } else {
      char msg[32];
      snprintf(msg, sizeof(msg), "Castiga: %c", winner);
      drawCenteredText(msg, 18, 2, RGB565_GREEN);
    }
  }
}

void drawGrid() {
  gfx->fillRect(boardX - 2, boardY - 2, boardSize + 4, boardSize + 4, RGB565_WHITE);
  gfx->fillRect(boardX, boardY, boardSize, boardSize, RGB565_BLACK);

  gfx->fillRect(boardX + cellSize - 2, boardY, 4, boardSize, RGB565_WHITE);
  gfx->fillRect(boardX + 2 * cellSize - 2, boardY, 4, boardSize, RGB565_WHITE);

  gfx->fillRect(boardX, boardY + cellSize - 2, boardSize, 4, RGB565_WHITE);
  gfx->fillRect(boardX, boardY + 2 * cellSize - 2, boardSize, 4, RGB565_WHITE);
}

void drawX(int cx, int cy) {
  int margin = 20;
  int x0 = boardX + cx * cellSize + margin;
  int y0 = boardY + cy * cellSize + margin;
  int x1 = boardX + (cx + 1) * cellSize - margin;
  int y1 = boardY + (cy + 1) * cellSize - margin;

  for (int i = -2; i <= 2; i++) {
    gfx->drawLine(x0 + i, y0, x1 + i, y1, RGB565_RED);
    gfx->drawLine(x0 + i, y1, x1 + i, y0, RGB565_RED);
  }
}

void drawO(int cx, int cy) {
  int centerX = boardX + cx * cellSize + cellSize / 2;
  int centerY = boardY + cy * cellSize + cellSize / 2;
  int radius = cellSize / 2 - 20;

  for (int i = 0; i < 4; i++) {
    gfx->drawCircle(centerX, centerY, radius - i, RGB565_CYAN);
  }
}

void drawMarks() {
  for (int r = 0; r < 3; r++) {
    for (int c = 0; c < 3; c++) {
      if (board[r][c] == 'X') drawX(c, r);
      if (board[r][c] == 'O') drawO(c, r);
    }
  }
}

void drawResetButton() {
  gfx->fillRoundRect(resetBtnX, resetBtnY, resetBtnW, resetBtnH, 10, RGB565_BLUE);
  gfx->drawRoundRect(resetBtnX, resetBtnY, resetBtnW, resetBtnH, 10, RGB565_WHITE);

  gfx->setTextSize(2);
  gfx->setTextColor(RGB565_WHITE);
  gfx->setCursor(resetBtnX + 28, resetBtnY + 16);
  gfx->print("RESTART");
}

void drawUI() {
  gfx->fillScreen(RGB565_BLACK);
  drawStatus();
  drawGrid();
  drawMarks();
  drawResetButton();
}

bool inResetButton(int x, int y) {
  return (x >= resetBtnX && x < resetBtnX + resetBtnW &&
          y >= resetBtnY && y < resetBtnY + resetBtnH);
}

bool inBoard(int x, int y) {
  return (x >= boardX && x < boardX + boardSize &&
          y >= boardY && y < boardY + boardSize);
}

void handleBoardTouch(int x, int y) {
  if (!inBoard(x, y) || gameOver) return;

  int col = (x - boardX) / cellSize;
  int row = (y - boardY) / cellSize;

  if (row < 0 || row > 2 || col < 0 || col > 2) return;
  if (board[row][col] != ' ') return;

  board[row][col] = currentPlayer;

  winner = checkWinner();
  if (winner != ' ') {
    gameOver = true;
  } else {
    currentPlayer = (currentPlayer == 'X') ? 'O' : 'X';
  }

  drawUI();
}

void setup() {
  Serial.begin(115200);
  delay(200);

  pinMode(PIN_LCD_BL, OUTPUT);
  digitalWrite(PIN_LCD_BL, HIGH);

  pinMode(PIN_TP_INT, INPUT_PULLUP);
  pinMode(PIN_TP_RST, OUTPUT);

  digitalWrite(PIN_TP_RST, LOW);
  delay(20);
  digitalWrite(PIN_TP_RST, HIGH);
  delay(200);

  Wire.begin();
  Wire.setClock(400000);

  if (!gfx->begin()) {
    Serial.println("gfx->begin() failed!");
    while (1) delay(100);
  }

  gfx->fillScreen(RGB565_BLACK);

  resetGame();
  drawUI();
}

void loop() {
  int tx, ty;
  bool touched = readTouchScreen(tx, ty);

  if (touched) {
    unsigned long now = millis();
    if (now - lastTouchTime > touchDebounceMs) {
      lastTouchTime = now;

      Serial.print("Touch: ");
      Serial.print(tx);
      Serial.print(", ");
      Serial.println(ty);

      if (inResetButton(tx, ty)) {
        resetGame();
        drawUI();
      } else {
        handleBoardTouch(tx, ty);
      }
    }
  }

  delay(10);
}

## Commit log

2026-05-11 Update Game_Consoles.ino
    Replaced the BMP boot intro player with a RAW565
    // video player using /intro/frame_001.raw through /intro/frame_075.raw.
2026-05-11 Add Datasheets
    added datasheets
    [PINs.xlsx]
2026-05-11 add 4 sec to frame_00
    2026-05-11 18:40 +02:00 - Added a 4 second hold on frame_000.raw before the
    // rest of the RAW intro animation plays.
    // 2026-05-11 18:05 +02:00 - Set RAW intro pla
2026-05-11 add new home screed
    // 2026-05-11 18:52 +02:00 - Added an SD-loaded home screen after the intro with
    // background and Games, Settings, and Exit RAW buttons.
2026-05-11 added Home button
    Moved the Tic Tac Toe Home button to the game mode
    // menu page with Local, Host, Join, and Reset Score.
2026-05-14 CAD Files
    Added initial CAD Files
    [3.5inch Capacitive Touch LCD.dwg, Carcasa_v0001-BodyFillet.step]
2026-05-14 2 step host setup
    flow similar like in JOIN, select predefined WiFi SSID then set up IP .
2026-05-20 CAD & RPSLS_game asets, drawio files
    CAD & RPSLS_game asets, drawio files
    [NanoESP32.PrjPcb, TOP.SchDoc]
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2026-05-20 rpsls_wheel.raw image used instead of the drawn circle with segments
    Switched the RPSLS choice screen to use the
    // SD-loaded /RPSLS_game/general/rpsls_wheel.raw image while keeping invisible // touch segments for selection.
2026-05-27 Changed game mode menu Home buttons to Back buttons that return to the Games selection screen.
    Changed game mode menu Home buttons to Back buttons that return to the Games selection screen.
2026-05-27 Added network Host/Join gameplay for RPSLS using the same WiFi setup flow and hidden-choice result logic as local play.
    Added network Host/Join gameplay for RPSLS using the same WiFi setup flow and hidden-choice result logic as local play.
2026-05-27 Replaced Battleship with a Pocket Tanks menu and added first local artillery gameplay with destructible terrain
    Replaced visible BATTLESHIP button with POCKET TANKS.
    New Pocket Tanks menu with LOCAL, HOST, JOIN, RESET SCOR, BACK.
    Local Pocket Tanks gameplay:
    2 tanks
    generated destructible terrain
    angle and power controls
    turn-by-turn firing
    projectile physics
    terrain/tank collision
    crater explosion
    winner/result screen
    persistent P1/P2 score and reset score
    Host/Join buttons currently show “Network mode coming soon”,
2026-05-27 Smoothed Pocket Tanks projectile animation by redrawing only the projectile area with a fixed frame time.
    proiectilul nu mai redesenează tot ecranul la fiecare frame. Acum:
    scena se desenează o singură dată înainte de tragere;
    se șterge doar zona mică unde a fost proiectilul;
    se redesenează doar proiectilul nou;
    frame time-ul este fixat la 24 ms, deci mișcarea ar trebui să fie mult mai constantă.
2026-05-27 Added randomized Pocket Tanks terrain , Removed Pocket Tanks full-screen redraws from angle and power controls to reduce UI flicker.
    POWER +/- nu mai redesenează tot ecranul, doar panoul de control.
    ANGLE +/- nu mai redesenează tot ecranul, doar zona tancului curent/barrelului și panoul de control.
    Am adăugat restore parțial pentru background/terrain în zona afectată.
    Randomized terrain waves, amplitudes, phases, base height, and tank platform heights.
2026-05-28 Added explanatory comments across the main source blocks to make hardware, UI, networking, and game logic easier to read.
    I added explanatory comments across the main source blocks:
    hardware/config
    app state and layout
    RAW/SD asset drawing
    score storage
    touch and drawing helpers
    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
2026-06-03 Added Arduino Nano ESP32 board-label and physical-header comments for each configured GPIO.
    Added Arduino Nano ESP32 board-label and physical-header comments for each configured GPIO.
2026-06-03 Added some CAD and deleted some library examples
    Added some CAD and deleted some library examples
    [18650 minimal holder.step, 18650_minimal_holder.stl, 18650x2vaseCctHldr.stl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]
2026-06-03 Games and Tic Tac Toe menu buttons to transparent
    Changed Games and Tic Tac Toe menu buttons to transparent arcade text buttons with consistent two-color lettering.
2026-06-03 Rock-Paper-Scissors arcade menu background and switched its menu to the transparent arcade text buttons.
    Ported the Rock-Paper-Scissors arcade menu background and switched its menu to the transparent arcade text buttons.
2026-06-17 Fallback screen for home
    HOME now has a generated arcade fallback screen when /home_screen/background.raw or SD assets are missing.
    The fallback uses the same style as GAMES, but with:
    HOME as the main marquee text
    MAIN MENU as subtitle
    the existing fallback buttons still drawn afterward if their RAW button assets are missing
2026-06-17 Tanks Wars can be played in Network
    Tanks Wars now uses the same Host/Join setup flow as Tic Tac Toe and RPSLS.
    Added NETWORK_GAME_PT / protocol code PT.
    Host sends a synced terrain seed via START:PT:<seed> and NEW:PT:<seed>.
    Angle, power, and fire are synced with:PT_ANGLE
    PT_POWER
    PT_FIRE
    Network turns are enforced: only the active player can adjust/fire.
    Tanks Wars menu now says LOCAL / NETWORK.
    Host/Join no longer open placeholder pages.
2026-06-17 TankWars has fallback background and buttons are now same as other games
    Tanks Wars menu now has a generated arcade fallback background with a neon title, tank decorations, battlefield terrain, projectile sparks, and arcade framing.
    I also changed the Tanks Wars menu buttons to the same transparent arcade text style used by Tic Tac Toe:
    LOCAL, HOST, JOIN, RESET SCOR, BACK
2026-06-17 New local game Breakout
    Added STATE_BREAKOUT_PLAYING.
    Pressing LOCAL in Breakout now starts a playable portrait Breakout game.
    Added bricks, paddle, ball physics, lives, score, win/game-over overlay, restart tap, and MENU button.
    Main loop now updates Breakout at a fixed 20 ms frame step for smoother motion.
2026-06-17 Made Breakout playable over network.
    Added a generated Breakout arcade fallback background with marquee, bricks, playfield, paddle, ball trail, and neon menu slots.
    Changed the Breakout menu buttons to the same transparent two-color arcade text style used by Tic Tac Toe.
    Breakout now supports network play through the same Host/Join flow as the other games.
    Implemented:
    Added NETWORK_GAME_BREAKOUT with network code BRK.
    Breakout HOST now opens the Host setup flow.
    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
2026-06-17 Added PONG local mode
    PONG button on the second Games page, under BREAKOUT.
    New Pong menu with LOCAL, HOST, JOIN, BACK.
    Local playable Pong:player paddle at bottom
    CPU paddle at top
    touch left/right buttons plus direct lower-court touch movement
    first to 5 wins
    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
2026-06-18 Added Ranch Game
    RANCH RUSH button on the Games MORE page.
    New Ranch Rush menu with LOCAL, HOST, JOIN, BACK.
    Ranch-themed fallback background using the needed visual parts from the attached code: field, fences, lanes, cowboy/lasso, cattle, title sign.
    Ranch Rush network code ID: RANCH, wired into the shared Host/Join setup flow.
    Host/Join waiting screens now show RANCH HOST / RANCH JOIN.
    Placeholder screens for Local/Host/Join until the full Ranch Rush gameplay is integrated.
    Ranch Rush local gameplay with 5 lanes, cowboy movement, lasso, animal spawning, collisions, lives, score, level, and game over restart.
    Cow/bull/horse-style animal rendering with different point values.
    Persistent Ranc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
2026-06-18 New Games page with FROGGER.
    New Games page with FROGGER.
    Frogger menu with LOCAL, HOST, JOIN, BACK.
    Local playable Frogger based on the attached code: roads, cars, river, logs, lily pads, lives, score, levels, high score.
    Frogger Host/Join routing through the existing WiFi setup flow, currently opening a Frogger network placeholder.
2026-06-27 SolidWorks parts and some pictures
    SolidWorks parts and some pictures
    [016_Suport_OLED_PCB-PCB_EPȘZON.step, 016_Suport_OLED_PCB-Support_OLED.SLDPRT, 016_Suport_OLED_PCB-Support_OLED.iges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]
2026-07-01 Added a looping arcade-style background melody for the buzzer
    plays automatically in non-game screens like Home, Games, Settings, Host/Join setup, waiting screens, menus
    stops automatically during actual gameplay
    existing beep/click/win sounds get priority and briefly mute the background melody
    based on the attached MP3 as a monophonic chiptune-style version suitable for tone()/buzzer hardware
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2026-07-01 added Resetr Score buttons and igh scores on every game
2026-07-01 Added Hex Pipes to the Games
    Added Hex Pipes to the Games menu on the third page, with its own game menu:
    LOCAL
    HOST
    JOIN
    RESET SCORE
    BACK
    Implemented the local playable Hex Pipes puzzle from the attached code: hex grid, pipe rotation, move/time HUD, solved screen, best moves/time storage, and reset score. Host/Join currently open a clear “network mode coming soon” placeholder page.
    Also kept the required reference on the Hex Pipes main page:
    Inspired by hexapipes.vercel.app
2026-07-01 dded network Hex Pipes gameplay
    Hex Pipes Host/Join now use the shared WiFi setup flow.
    Network games use a shared puzzle seed, so both players get the same board.
    HUD shows visible P1 and P2 move counters plus timer.
    Added HEX_STATE network sync for moves, time, and solved status.
    Winner logic: first solved wins; if both solve in the same displayed time, fewer moves wins; exact tie becomes draw.
2026-07-01 fixed some TicTacToe network problems, added Pics from Games
    Tic Tac Toe Join now auto-selects the configured Host SSID, or any known Host SSID from the epic list if the exact one is not found.
    Join TCP connection attempts are now throttled instead of retrying every loop.
    WiFi sleep is disabled during Host/Join.
    TCP setNoDelay(true) is enabled for lower latency and more stable message delivery.
    Added Serial debug: Join TCP attempt X to <IP>.
2026-07-01 Extra SOlidWOrks parts
    [3.5inch Capacitive Touch LCD.dwg, Assembly_test.SLDDRW, DisplayCase_Back_v0011_simple.SLDPRT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]
